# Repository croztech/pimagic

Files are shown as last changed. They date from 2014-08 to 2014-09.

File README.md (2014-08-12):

PiMagic Interface Board Repository
==================================

Created by @croz_tech (http://croztech.wordpress.com/)

PiMagic repository contents:

hardware......... EAGLE hardware design files (schematic & PCB)

ana_pong.py...... Version of the popular Pong game using analogue paddle inputs

firmata_rgb.py... Random RGB LED mood lamp using PWM outputs of the PiMagic

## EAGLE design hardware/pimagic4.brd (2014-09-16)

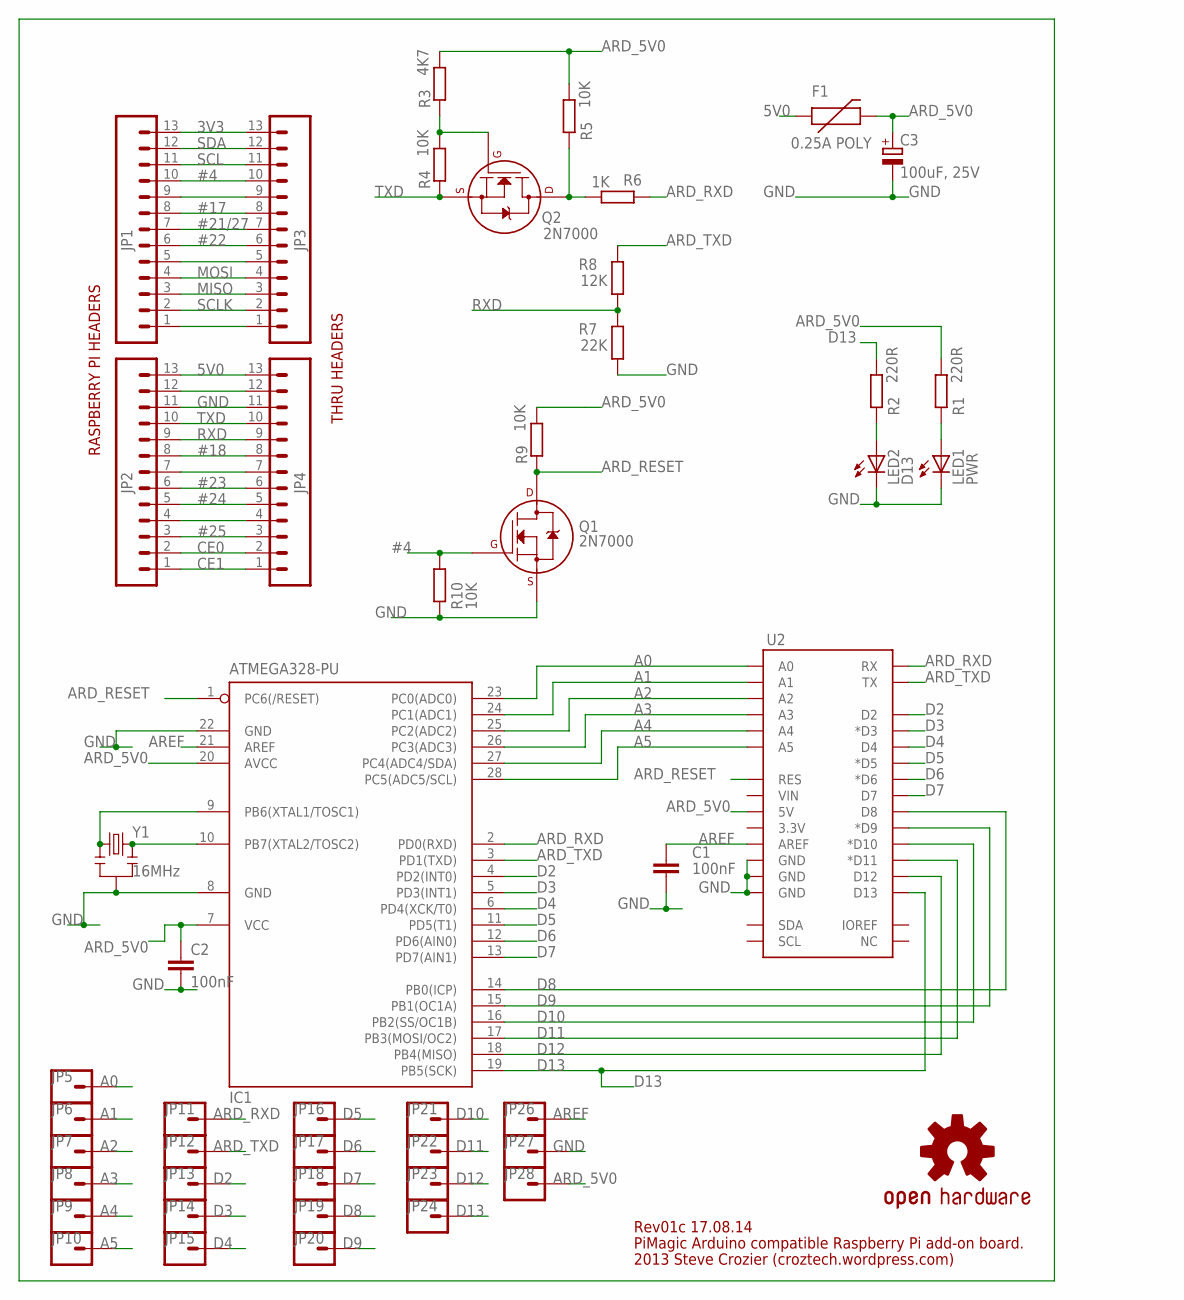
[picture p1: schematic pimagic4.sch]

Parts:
C1, C2: 100nF; C5B2.5
C3: 100uF, 25V; E2,5-6
F1: 0.25A POLY; PTC
IC1: ATMEGA328-PU; DIL28-3
JP1, JP2, JP3, JP4: M13; 1X13
JP5, JP6, JP7, JP8, JP9, JP10, JP11, JP12, JP13, JP14, JP15, JP16, JP17, JP18, JP19, JP20, JP21, JP22, JP23, JP24, JP26, JP27, JP28: M01PTH; 1X01
LED1: PWR; LED3MM
LED2: D13; LED3MM
Q1, Q2: 2N7000; TO-92
R1, R2: 220R; 0207/10
R3: 4K7; 0207/10
R4, R5, R9, R10: 10K; 0207/10
R6: 1K; 0207/10
R7: 22K; 0207/10
R8: 12K; 0207/10
U2: ARDUINO_SHIELDLONGPADS; DUEMILANOVE_SHIELD_LONGPADS
U$1: OSHW-LOGOM; OSHW-LOGO-M
Y1: 16MHz; RESONATOR-PTH

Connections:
3V3: JP1.13, JP3.13
5V0: F1.P$1 (1), JP2.13, JP4.13
#4: JP1.10, JP3.10, Q1.2 (G), R10.2
#17: JP1.8, JP3.8
#18: JP2.8, JP4.8
#21/27: JP1.7, JP3.7
#22: JP1.6, JP3.6
#23: JP2.6, JP4.6
#24: JP2.5, JP4.5
#25: JP2.3, JP4.3
A0: IC1.23 (PC0(ADC0)), JP5.1, U2.A0
A1: IC1.24 (PC1(ADC1)), JP6.1, U2.A1
A2: IC1.25 (PC2(ADC2)), JP7.1, U2.A2
A3: IC1.26 (PC3(ADC3)), JP8.1, U2.A3
A4: IC1.27 (PC4(ADC4/SDA)), JP9.1, U2.A4
A5: IC1.28 (PC5(ADC5/SCL)), JP10.1, U2.A5
ARD_5V0: C2.1, C3.+, F1.P$2 (2), IC1.7 (VCC), IC1.20 (AVCC), JP28.1, R1.2, R3.2, R5.2, R9.2, U2.5V
ARD_RESET: IC1.1 (PC6(/RESET)), Q1.3 (D), R9.1, U2.RES
ARD_RXD: IC1.2 (PD0(RXD)), JP11.1, R6.1, U2.RX
ARD_TXD: IC1.3 (PD1(TXD)), JP12.1, R8.1, U2.TX
AREF: C1.1, IC1.21 (AREF), JP26.1, U2.AREF
CE0: JP2.2, JP4.2
CE1: JP2.1, JP4.1
D2: IC1.4 (PD2(INT0)), JP13.1, U2.D2
D3: IC1.5 (PD3(INT1)), JP14.1, U2.D3 (*D3)
D4: IC1.6 (PD4(XCK/T0)), JP15.1, U2.D4
D5: IC1.11 (PD5(T1)), JP16.1, U2.D5 (*D5)
D6: IC1.12 (PD6(AIN0)), JP17.1, U2.D6 (*D6)
D7: IC1.13 (PD7(AIN1)), JP18.1, U2.D7
D8: IC1.14 (PB0(ICP)), JP19.1, U2.D8
D9: IC1.15 (PB1(OC1A)), JP20.1, U2.D9 (*D9)
D10: IC1.16 (PB2(SS/OC1B)), JP21.1, U2.D10 (*D10)
D11: IC1.17 (PB3(MOSI/OC2)), JP22.1, U2.D11 (*D11)
D12: IC1.18 (PB4(MISO)), JP23.1, U2.D12
D13: IC1.19 (PB5(SCK)), JP24.1, R2.2, U2.D13
GND: C1.2, C2.2, C3.-, IC1.8 (GND), IC1.22 (GND), JP2.11, JP4.11, JP27.1, LED1.K (C), LED2.K (C), Q1.1 (S), R7.2, R10.1, U2.GND@0 (GND), U2.GND@1 (GND), U2.GND@2 (GND), Y1.2
MISO: JP1.3, JP3.3
MOSI: JP1.4, JP3.4
unnamed: JP1.5, JP3.5
unnamed: JP1.1, JP3.1
unnamed: Q2.2 (G), R3.1, R4.2
unnamed: IC1.9 (PB6(XTAL1/TOSC1)), Y1.1
unnamed: JP1.9, JP3.9
unnamed: IC1.10 (PB7(XTAL2/TOSC2)), Y1.3
unnamed: Q2.3 (D), R5.1, R6.2
unnamed: LED2.A, R2.1
unnamed: LED1.A, R1.1
unnamed: JP2.12, JP4.12
unnamed: JP2.7, JP4.7
unnamed: JP2.4, JP4.4
RXD: JP2.9, JP4.9, R7.1, R8.2
SCL: JP1.11, JP3.11
SCLK: JP1.2, JP3.2
SDA: JP1.12, JP3.12
TXD: JP2.10, JP4.10, Q2.1 (S), R4.1

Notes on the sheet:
RASPBERRY PI HEADERS
THRU HEADERS
PiMagic Arduino compatible Raspberry Pi add-on board.
2013 Steve Crozier (croztech.wordpress.com)
Rev01c 17.08.14

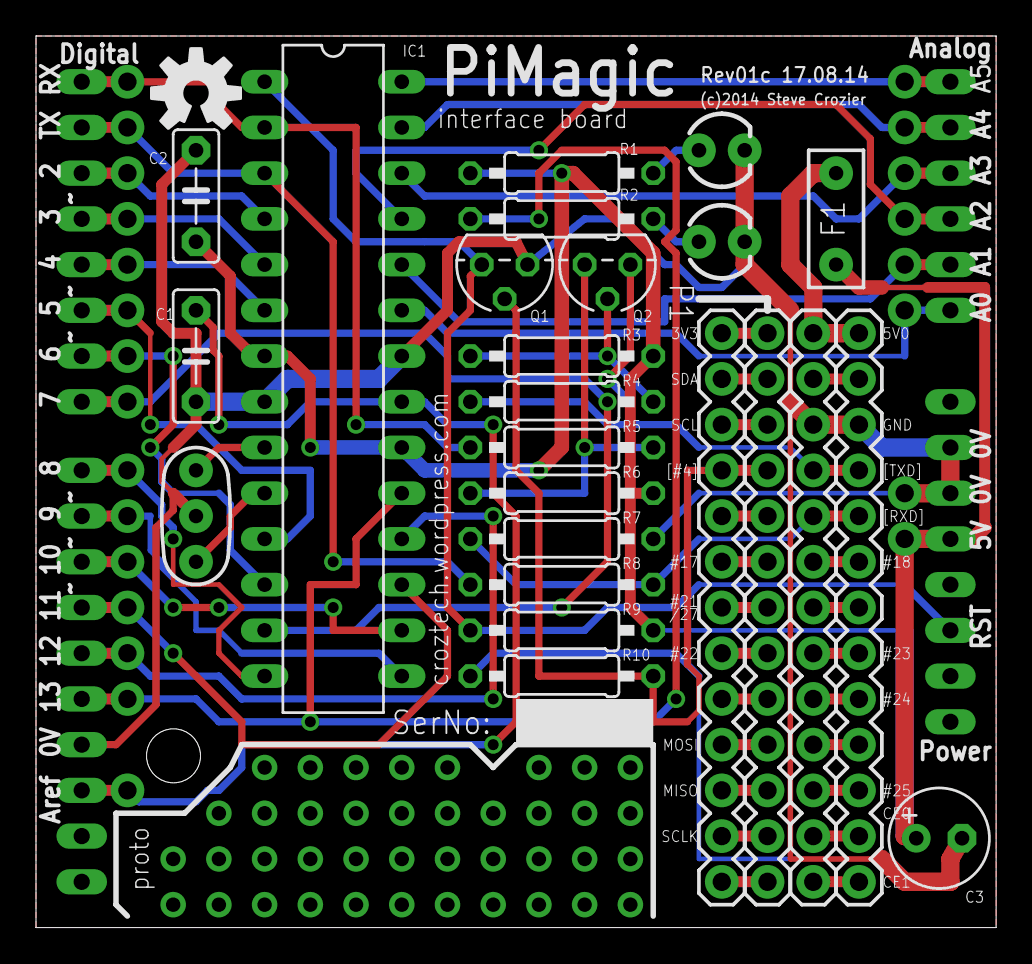
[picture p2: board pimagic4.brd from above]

Board: 2 copper layers, 53.3 x 49.5 mm, 49 parts (1 on the bottom side), 55 nets.

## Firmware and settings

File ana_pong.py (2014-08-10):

#!/usr/bin/env python

# Analogue PiPong using the PiMagic interface board, channels A0/A1
# ( based on the original PiPong by Liam Fraser - 28/07/2012.
#    www.linuxuser.co.uk/tutorials/make-a-game-on-raspberry-pi )
# @croz_tech   V1.0  21/09/2013  (Steve Crozier)
#              - Note that the first version has only one analogue paddle on A0
# @croz_tech   V1.1  10/08/2014  (Steve Crozier)
#              - Fixed the window title
# @croz_tech   V1.2  10/08/2014  (Steve Crozier)
#              - Added second channel code
#              - Removed unused methods now the keyboard isn't used


import pygame # Provides what we need to make a game
import sys # Gives us the sys.exit function to close our program
import random # Can generate random positions for the pong ball
import pyfirmata # Connection/comms to the PiMagic with firmata protocol

from pygame.locals import *
from pygame import *

# Our main game class
class PiPong:
	
	def __init__(self):
		
		# Make the display size a member of the class
		self.displaySize = (640, 480)
		
		# Initialize pygame
		pygame.init()
		
		# Create a clock to manage time
		self.clock = pygame.time.Clock()
		
		# Set the window title
		display.set_caption("Analogue Pi Pong using PiMagic")
		
		# Create the window
		self.display = display.set_mode(self.displaySize)
			
		# Create the background, passing through the display size
		self.background = Background(self.displaySize)
	
		# Create a board object for the piMagic
		self.board=pyfirmata.Arduino('/dev/ttyAMA0')
		
		# Start an interator thread to prevent buffer overflow
		self.iter8 = pyfirmata.util.Iterator(self.board)
		self.iter8.start()
		
		# Set up pins
		# A0.. analogue input
		self.pin0 = self.board.get_pin('a:0:i')
		self.pin1 = self.board.get_pin('a:1:i')
		
		# Discard reads until A0/A1 read valid
		while self.pin0.read() is None:
			pass
		while self.pin1.read() is None:
			pass
		
		# Create two bats, a ball and add them to a sprite group
		self.player1Bat = Bat(self.displaySize, "player1")
		self.player2Bat = Bat(self.displaySize, "player2")
		self.ball = Ball(self.displaySize)
		self.sprites = sprite.Group(self.player1Bat, self.player2Bat,
		self.ball)
		
	
	def run(self):
		# Runs the game loop
		
		while True:
			# The code here runs when every frame is drawn
					
			# Handle Events
			self.handleEvents()
			
			# Draw the background
			self.background.draw(self.display)
						
			# Update and draw the sprites
			self.sprites.update()
			self.sprites.draw(self.display)
			
			# Check for bat collisions
			self.ball.batCollisionTest(self.player1Bat)
			self.ball.batCollisionTest(self.player2Bat)
			
			# Update the full display surface to the screen
			display.update()
			
			# Read the analogue paddle(s)
			self.bat1pos = self.pin0.read()
			self.player1Bat.moveTo(self.bat1pos)
			self.bat2pos = self.pin1.read()
			self.player2Bat.moveTo(self.bat2pos)
			
			# Limit the game to 30 frames per second
			self.clock.tick(30)
			
	def handleEvents(self):
		
		# Handle events, starting with the quit event
		for event in pygame.event.get():
			if event.type == QUIT:
				pygame.quit()
				self.board.exit()
				sys.exit()

				
# The class for the background
class Background:
	
	def __init__(self, displaySize):
		
		# Set our image to a new surface, the size of the screen rectangle
		self.image = Surface(displaySize)
		
		# Fill the image with a green colour (specified as R,G,B)
		self.image.fill((27, 210, 57))
		
		# Get width proportionate to display size
		lineWidth = displaySize[0] / 80
		
		# Create a rectangle to make the white line
		lineRect = Rect(0, 0, lineWidth, displaySize[1])
		lineRect.centerx  = displaySize[0] / 2
		draw.rect(self.image, (255, 255, 255), lineRect)
		
	def draw(self, display):
			
		# Draw the background to the display that has been passed in
		display.blit(self.image, (0,0))

# The class for the bats on either side
class Bat(sprite.Sprite):
	
	def __init__(self, displaySize, player):
			
		# Initialize the sprite base class
		super(Bat, self).__init__()
		
		# Make player a member variable
		self.player = player
		
		# Get a width and height values proportionate to the display size
		width = displaySize[0] / 80
		height = displaySize[1] / 6
		self.dispheight = displaySize[1]
		
		# Create an image for the sprite using the width and height
		# we just worked out
		self.image = Surface((width, height))
		
		# Create the sprites rectangle from the image
		self.rect = self.image.get_rect()
		
		# Set the rectangle's location depending on the player
		if player == "player1":
			# Left side
			self.rect.centerx = displaySize[0] / 20
			# Fill dark green
			self.image.fill((0, 128, 0))
		elif player == "player2":
			# Right side
			self.rect.centerx = displaySize[0] - displaySize[0] / 20
			# Fill dark red
			self.image.fill((128, 0, 0))
		
		# Center the rectangle vertically
		self.rect.centery = displaySize[1] / 2
		
		
	def moveTo(self,pos):
		
		self.rect.centery = (self.dispheight)*pos

# The class for the ball
class Ball(sprite.Sprite):
	
	def __init__(self, displaySize):
			
		# Initialize the sprite base class
		super(Ball, self).__init__()
		
		# Get the display size for working out collisions later
		self.displaySize = displaySize
		
		# Get a width and height values proportionate to the display size
		width = displaySize[0] / 30
		height = displaySize[1] / 30
		
		# Create an image for the sprite
		self.image = Surface((width, height))
		
		# Fill the image blue
		self.image.fill((27, 224, 198))
		
		# Create the sprites rectangle from the image
		self.rect = self.image.get_rect()
			
		# Work out a speed
		self.speed = displaySize[0] / 110
	
		# Reset the ball
		self.reset()
	
	def reset(self):
		
		# Start the ball directly in the centre of the screen
		self.rect.centerx = self.displaySize[0] / 2
		self.rect.centery = self.displaySize[1] / 2
		
		# Start the ball moving to the left or right (pick randomly)
		# Vector(x, y)
		if random.randrange(1, 3) == 1:
			# move to left
			self.vector = (-1, 0)
		else:
			# move to right
			self.vector = (1, 0)
	
	def update(self):
		
		# Check if the ball has hit a wall
		if self.rect.midtop[1] <= 0:
			# Hit top side
			self.reflectVector()
		elif self.rect.midleft[0] <= 0:
			# Hit left side
			self.reset()
		elif self.rect.midright[0] >= self.displaySize[0]:
			self.reset()
		elif self.rect.midbottom[1] >= self.displaySize[1]:
			# Hit bottom side
			self.reflectVector()
		
		# Move in the direction of the vector
		self.rect.centerx += (self.vector[0] * self.speed)
		self.rect.centery += (self.vector[1] * self.speed)
	
	def reflectVector(self):
		
		# Gets the current angle of the ball and reflects it, for bouncing
		# off walls
		deltaX = self.vector[0]
		deltaY = - self.vector[1]
		self.vector = (deltaX, deltaY)
		
		
	def batCollisionTest(self, bat):
	
		# Check if the ball has had a collision with the bat
		if Rect.colliderect(bat.rect, self.rect):
			
			# Work out the difference between the start and end points
			deltaX = self.rect.centerx - bat.rect.centerx
			deltaY = self.rect.centery - bat.rect.centery
			
			# Make the values smaller so it's not too fast
			deltaX = deltaX / 12
			deltaY = deltaY / 12
			
			# Set the balls new direction
			self.vector = (deltaX, deltaY)
			
if __name__ == '__main__':
	game = PiPong()
	game.run()

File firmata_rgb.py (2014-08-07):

#!/usr/bin/env python

# RGB random mood lamp on piMagic board
# Uses PWM~ outputs on pins 3, 5 and 6
# @croz_tech            V1.0 21/09/2013
import pyfirmata
import random
import sys
import os
from time import sleep

# Create a board object for the piMagic
board=pyfirmata.Arduino('/dev/ttyAMA0')

# Set up pins
# D3,5,6.. PWM outputs
pin3 = board.get_pin('d:3:p')
pin5 = board.get_pin('d:5:p')
pin6 = board.get_pin('d:6:p')

# Initialise last values to zero (LED elements all off)
oldred=0
oldgreen=0
oldblue=0

# Clear and print some instructions on the screen
os.system ('clear')
print '@croz_tech RGB random mood-lamp using PiMagic PWM...'
print 'Press CTRL+C to exit'
print
print '( R  ,  G  ,  B  )'
while True:
        try:
                # Get some random colours (0..1) levels
                newred=random.randint(0,100)/100.0
                newgreen=random.randint(0,100)/100.0
                newblue=random.randint(0,100)/100.0
                # Loop to fade (interpolate) from old to new colour
                for iter in range(0,11):
                        pin3.write(oldred+((newred-oldred)*(float(iter)/10)))
                        pin5.write(oldgreen+((newgreen-oldgreen)*(float(iter)/10)))
                        pin6.write(oldblue+((newblue-oldblue)*(float(iter)/10)))
                        # Adjust this (default=0.2sec) for slower/faster transition
                        sleep(0.2)
                # Display the new colour for debug
                print '(%.2f, %.2f, %.2f)' % (newred, newgreen, newblue)
                # Store this for the next transistion
                oldred=newred
                oldgreen=newgreen
                oldblue=newblue
                # Adjust this (default=2sec) for more/less frequent colour changes
                sleep (2)
        except KeyboardInterrupt:
                # CTRL+C interrupt - turn off LEDs and shut down nicely
                pin3.write(0)
                pin5.write(0)
                pin6.write(0)
                board.exit()
                print ' exit'
                print
                sys.exit()

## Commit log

2014-08-07 Create firmata_rgb.py
    Python Firmata test for PiMagic board. Use with an RGB LED connected on PWM pins D3,5,6
2014-08-10 Create ana_pong.py
    Analogue PiPong using the PiMagic interface board, channels A0/A1
    - Note that the first version has only one analogue paddle on A0
2014-08-10 Update ana_pong.py
    Fixed the window title
    [ana_pong.py]
2014-08-10 PiMagic hardware design
    Hardware design files (schematic & board layout) for Eagle CAD 6.4.x
    [pimagic4.brd, pimagic4.sch]
2014-09-16 Rev01c update
    - Q1/Q2 silkscreen corrected
    - some of the silkscreen logos are now corrected
    - there’s a nice ground plan copper pour added on both sides
    - files updated to Eagle 7.1.0 format
    [pimagic4.brd, pimagic4.sch]
2014-09-16 Gerber files for PCB production
    Rev01c
    Top and bottom copper (.GTL, .GBL)
    Top and bottom solder mask (.GTS, .GBS)
    Top silkscreen (.GTO)
    Drill file, 2.4 leading (.TXT)

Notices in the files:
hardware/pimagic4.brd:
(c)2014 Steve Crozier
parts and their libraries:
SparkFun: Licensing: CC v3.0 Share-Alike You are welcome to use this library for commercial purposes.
